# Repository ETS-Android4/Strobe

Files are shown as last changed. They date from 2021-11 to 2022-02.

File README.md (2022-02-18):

# Strobe
Repository contains Arduino program and Android application used for one of my physics projects in high school. The project was a device to show stroboscopic effect on a stream of water.
Embedded (Arduino) program controls the operation of the device like colors of RGB LEDs, electromagnet, water pump. Android app provides easy to use interface to remote change parameters (frequency, colors etc.) in realtime by bluetooth.

## Android app
| Home | Palette |
| - | - |
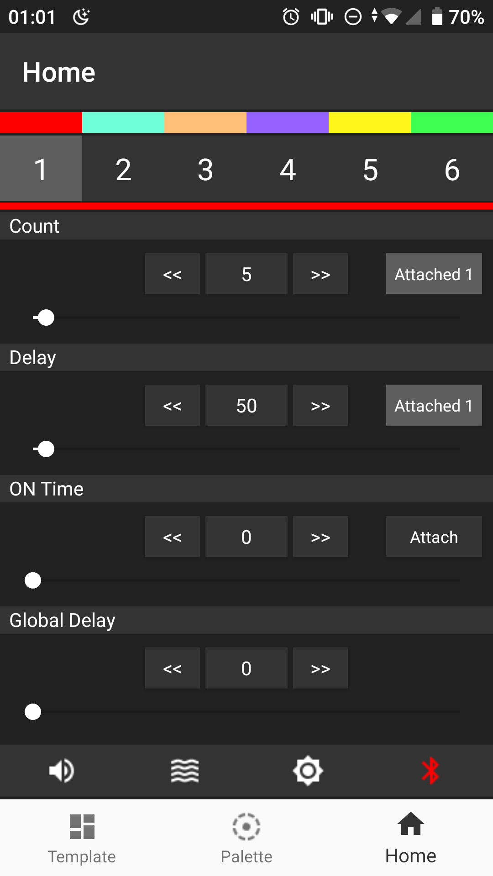
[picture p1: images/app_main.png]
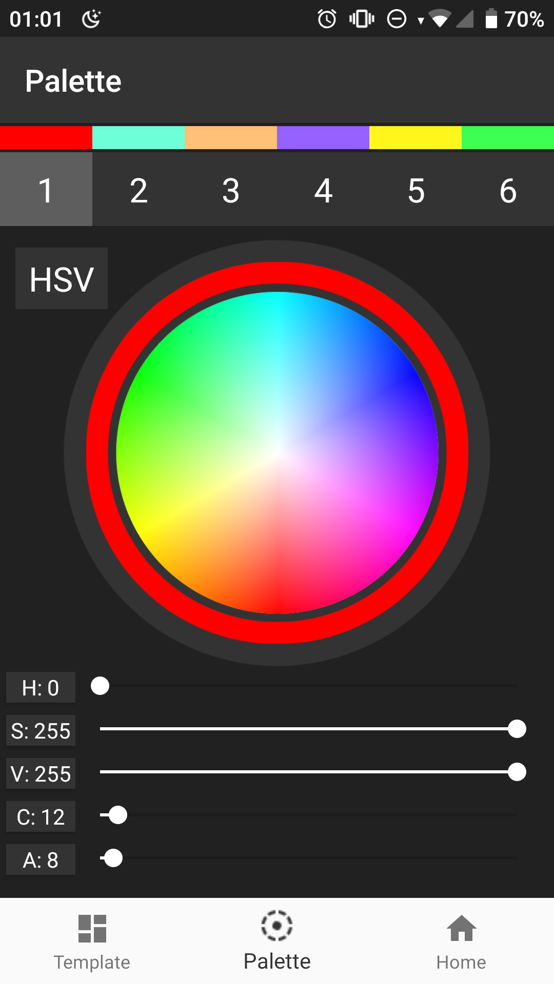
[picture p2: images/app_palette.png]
|  |  |

##### Android app tested only on Xiaomi mi A1

## Example of effects
| | | | |
|-|-|-| - |
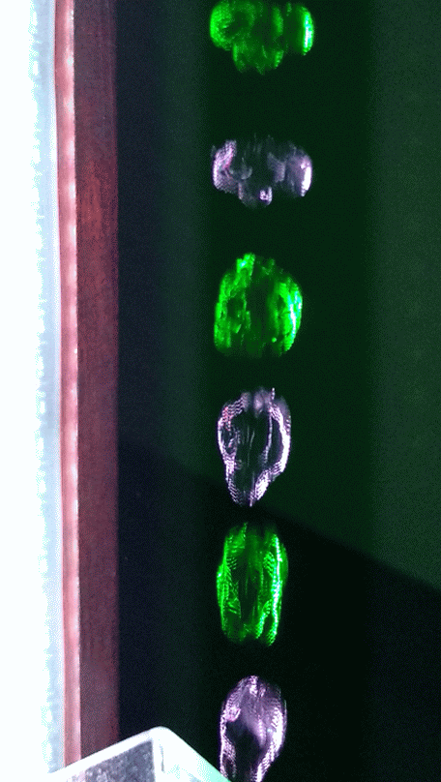
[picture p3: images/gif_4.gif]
| |  |  |  |

## Board

|||
|-|-|
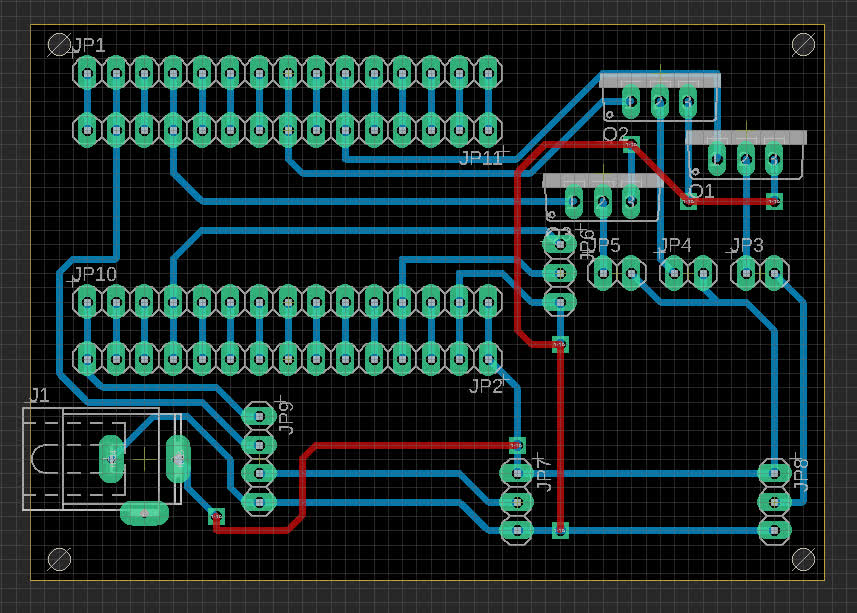
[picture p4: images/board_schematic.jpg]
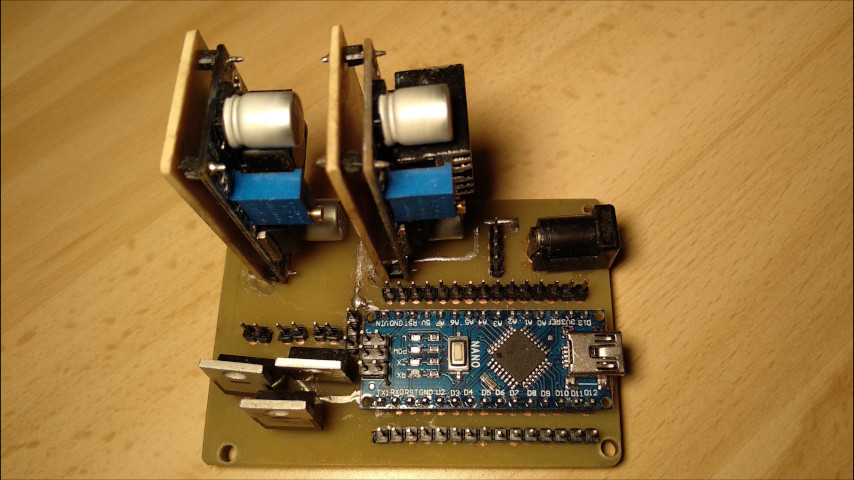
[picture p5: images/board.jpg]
|  | |

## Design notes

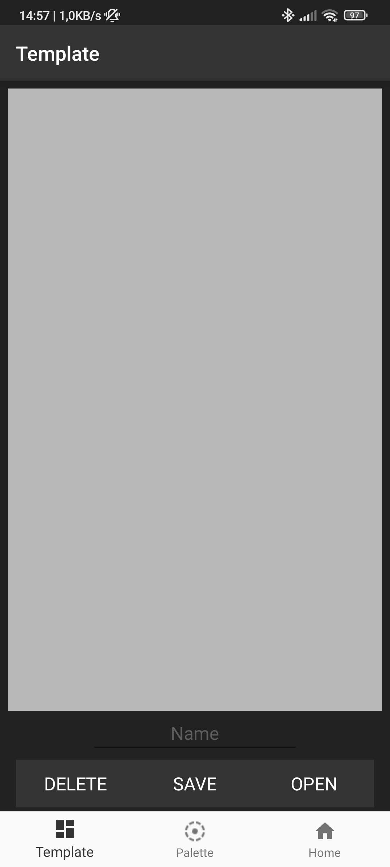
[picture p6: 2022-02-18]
images/app_template.jpg

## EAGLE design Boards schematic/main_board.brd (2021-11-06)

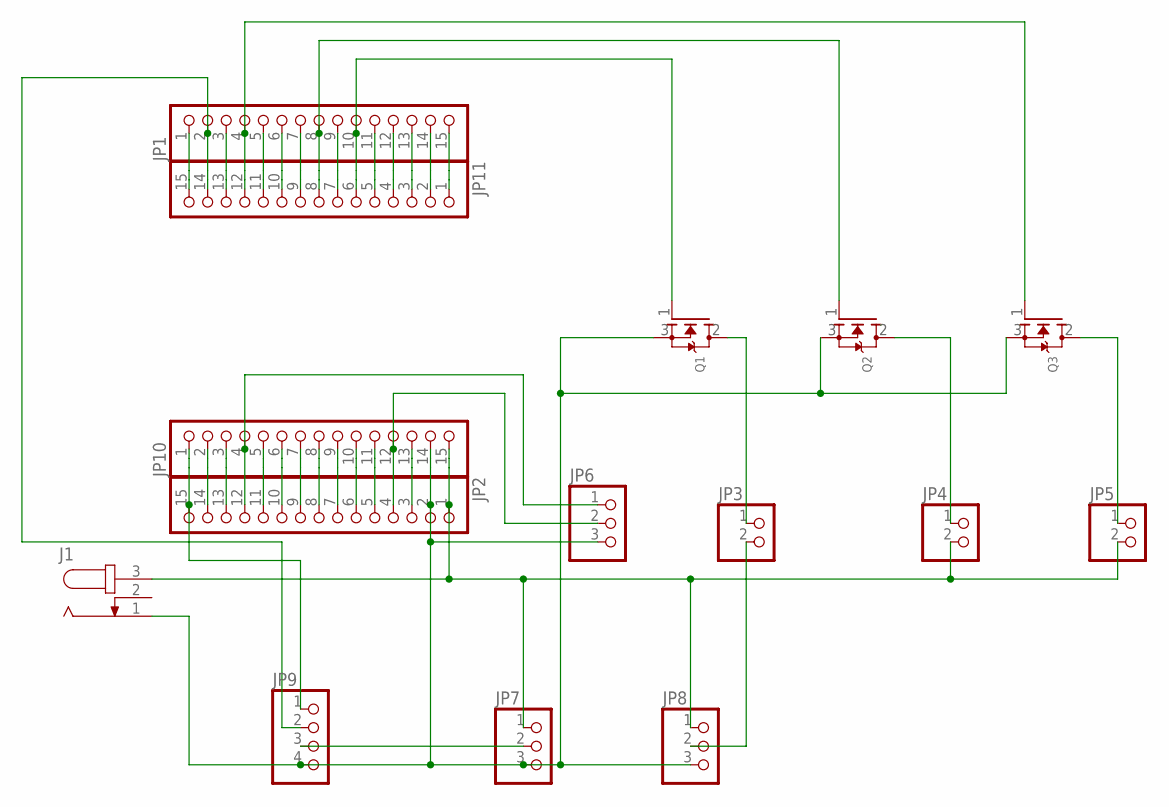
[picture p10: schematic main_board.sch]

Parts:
J1: JACK-PLUG1; SPC4078
JP1, JP2, JP10, JP11: PINHD-1X15; 1X15
JP3, JP4, JP5: PINHD-1X2; 1X02
JP6, JP7, JP8: PINHD-1X3; 1X03
JP9: PINHD-1X4; 1X04
Q1, Q2, Q3: MOSFET-NGDS_TO220V; TO220V

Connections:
unnamed: JP2.15, JP9.1, JP10.1
unnamed: JP2.14, JP10.2
unnamed: JP2.13, JP10.3
unnamed: JP2.12, JP6.1, JP10.4
unnamed: JP2.11, JP10.5
unnamed: JP2.10, JP10.6
unnamed: JP2.9, JP10.7
unnamed: JP2.8, JP10.8
unnamed: JP2.7, JP10.9
unnamed: JP2.6, JP10.10
unnamed: JP2.5, JP10.11
unnamed: JP2.4, JP6.2, JP10.12
unnamed: JP2.3, JP10.13
unnamed: J1.1, JP2.2, JP6.3, JP7.3, JP8.3, JP9.4, JP10.14, Q1.3 (S), Q2.3 (S), Q3.3 (S)
unnamed: J1.3, JP2.1, JP4.2, JP5.2, JP7.1, JP8.1, JP10.15
unnamed: JP1.15, JP11.1
unnamed: JP1.14, JP11.2
unnamed: JP1.13, JP11.3
unnamed: JP1.12, JP11.4
unnamed: JP1.11, JP11.5
unnamed: JP1.10, JP11.6, Q1.1 (G)
unnamed: JP1.9, JP11.7
unnamed: JP1.8, JP11.8, Q2.1 (G)
unnamed: JP1.7, JP11.9
unnamed: JP1.6, JP11.10
unnamed: JP1.5, JP11.11
unnamed: JP1.4, JP11.12, Q3.1 (G)
unnamed: JP1.3, JP11.13
unnamed: JP1.2, JP9.2, JP11.14
unnamed: JP1.1, JP11.15
unnamed: JP3.1, Q1.2 (D)
unnamed: JP4.1, Q2.2 (D)
unnamed: JP5.1, Q3.2 (D)
unnamed: JP3.2, JP8.2
unnamed: JP7.2, JP9.3

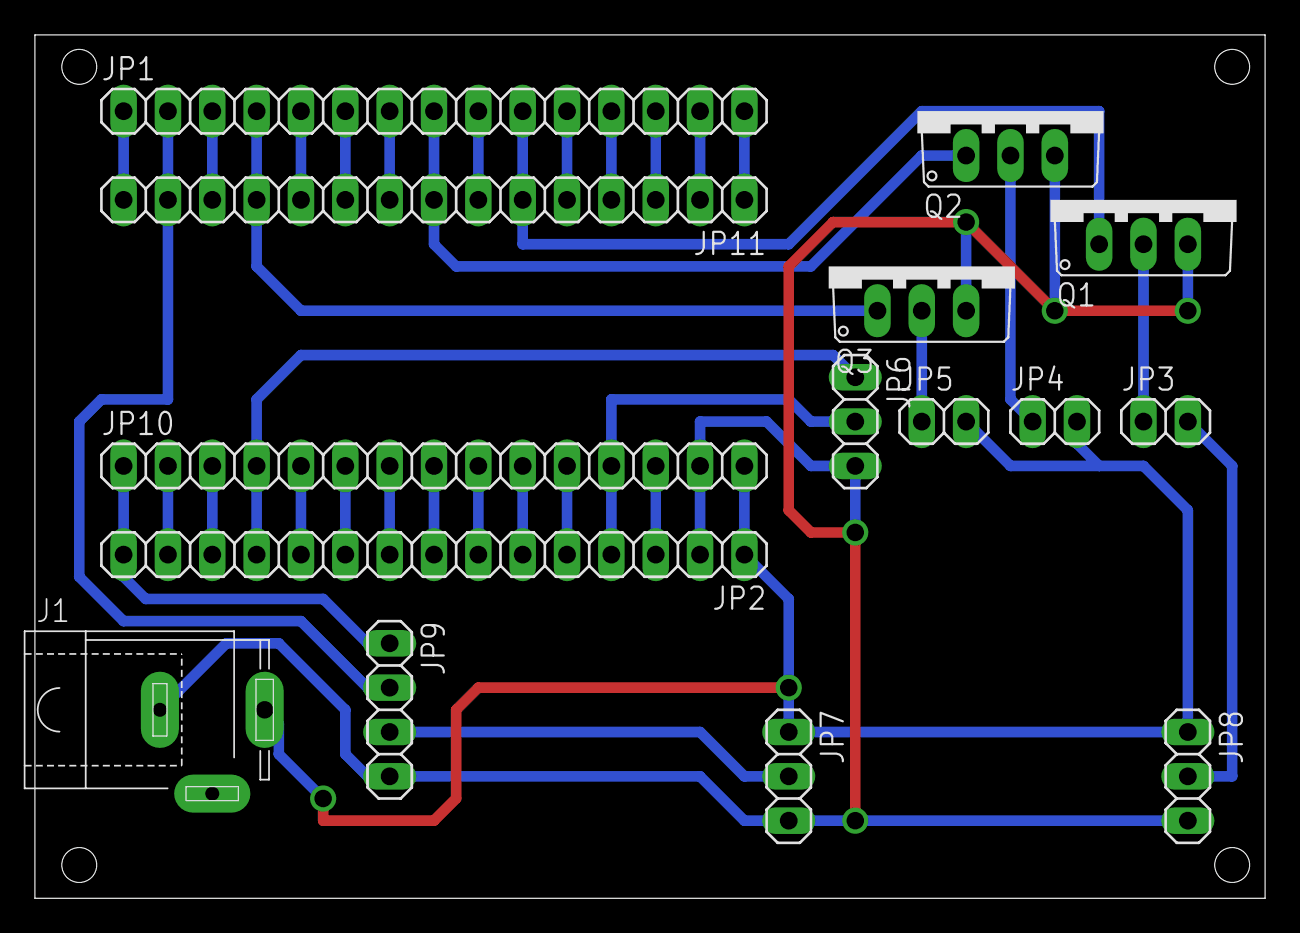
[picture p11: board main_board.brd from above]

Board: 2 copper layers, 70.5 x 49.5 mm, 15 parts (0 on the bottom side), 35 nets.

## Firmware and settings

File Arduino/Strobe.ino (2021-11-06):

#include <TimerOne.h>
#include <FastLED.h>

#define NP 64

#define Magnet 5
#define Pump 3

#define LED_max 20001

String string;
String sign;
char command, mark;
unsigned int l;
bool sync;

unsigned char colors[6][3], add_hsv[6]={0}, count_hsv[6]={1}, count[6]={2}, selected = 0, pumpValue, attachValue[8], c[6]={0}, add_color=0, mag=64;
unsigned short latency[6]={100}, onTime[6]={0}, global={1};
bool chosen[6], attachBool[8]= {false};
unsigned int pumpCount, ledCount=0, pot, x=1000;

int off, on;

CRGB leds[NP];
unsigned char startIndex = 0;
unsigned char brightness = 192;
bool LED = true;
bool model = true;
bool magnet = true;
bool pump = true;
bool Sync = false;

unsigned char magValue = 48;

void setup()
{
  chosen[0] = true;
  count[0]=2;
  latency[0]=1600;
  colors[0][0]=0;
  colors[0][1]=0;
  colors[0][2]=255;
 
  delay(1000);
  pinMode(Magnet, OUTPUT);
  pinMode(Pump, OUTPUT);
  
  FastLED.addLeds<APA102, 11, 13, BGR, DATA_RATE_MHZ(12)>(leds, NP);
  FastLED.setBrightness(192);
  
  Serial.begin(9600);
  Serial.setTimeout(200);

  Timer1.initialize(500);
  Timer1.attachInterrupt(pump_thread);
  
  delay(1000);  
}

void pump_thread(void){
  if(pump){
   if(pumpValue){
      if(pumpCount==pumpValue){
       digitalWrite(Pump, HIGH);}
     if(pumpCount>=40){
       digitalWrite(Pump, LOW);
       pumpCount=0;}
       pumpCount++;
    }
    else
      digitalWrite(Pump, HIGH);
  }
  else
    digitalWrite(Pump, LOW);
}

//Bluetooth
void Bluetooth(){
  if (Serial.available() > 0){
      string = "";
      l=0;
      mark = "";}
  while(Serial.available() > 0){
    command = ((byte)Serial.read());
    if(command == 'x')
      break;
    else{
      string += command;}
    delay(1);
  }
  Read();
  /*if(string!=""){
    Serial.print("String: "); Serial.println(string[string.length()-1]);
    Serial.print("Number: "); Serial.println(string.toInt());
  }*/
}

void Read(){
  mark = string[string.length()-1];
  l = string.toInt();
  switch(mark){
    case 'Q': switch(l){
      case 0: LED = true; break;
      case 1: LED = false; break;
      case 2: magnet = true; break;
      case 3: magnet = false; break;
      case 4: pump = true; break;
      case 5: pump = false; break;
      case 6: Sync = true; break;
      case 7: Sync = false; break;
    }
    //menu
    case 'b': brightness = l; FastLED.setBrightness(l); break;
    case 'p': pumpValue=l; break;
    case 'm': magValue=l; break;

    case 'P': x = l; break;
    //Palette
    case 'R': colors[selected][0] = l; break;
    case 'G': colors[selected][1] = l; break;
    case 'B': colors[selected][2] = l; break;
    case 'h': count_hsv[selected] = l; break;
    case 'v': add_hsv[selected] = l; c[selected]=0; break;
    //Home
    case 'S': selected = l; break;
    case 'A': for(int i=1; i<7;i++) {sign = string[i]; chosen[i-1]=sign.toInt();} break;
    case 'c': count[selected] = l; break;
    case 'd': latency[selected] = l; break;
    case 'o': onTime[selected] = l; break;
    case 'g': global = l; break;
    //Home attach
    case 'C': for(int i=1; i<9; i++){
      if(string[i]!='9'){
        attachBool[i-1]=true; sign = string[i]; attachValue[i-1]=sign.toInt();
      }else{attachBool[i-1]=false;}
      }break;
    case 'O': add_color = l; break;
  }
  l=0;
  mark = "";
  string = "";
}

void ledFunction(){
  char i=0, colorBuffer[3]={0}, countBuffer=0, latencyBuffer=0, onBuffer=0, hBuffer=0, aBuffer=0;
  
      if(attachBool[0]){
        countBuffer = attachValue[0];}
      if(attachBool[1]){
        latencyBuffer = attachValue[1];}
      if(attachBool[2]){
        onBuffer = attachValue[2];}
      if(attachBool[3]){
        colorBuffer[0] = 0;}
      if(attachBool[4]){
        colorBuffer[1] = 0;}
      if(attachBool[5]){
        colorBuffer[2] = 0;}
      if(attachBool[6]){
        hBuffer = 0;}
      if(attachBool[7]){
        aBuffer = 0;}
        
  if(LED){
    while(i<6){
      if(ledCount%count[countBuffer]==1){
        if(chosen[i]){
          fill_solid(leds, NP, CHSV(colors[colorBuffer[0]][0]+c[i]+add_color*(i), colors[colorBuffer[1]][1], colors[colorBuffer[2]][2]));
          FastLED.show();
          delayMicroseconds(onTime[onBuffer]*10);
        }else{
          //delayMicroseconds(824);
        }
        FastLED.clear();
        FastLED.show();
        delayMicroseconds(latency[latencyBuffer]*10);
      }
      if(count_hsv[hBuffer]==1||add_hsv[aBuffer]==0){
         c[i]=0;}
      if(ledCount%count_hsv[hBuffer]==1){
        c[i]+=add_hsv[aBuffer];}
      i++;
      
      if(!attachBool[0]){
        countBuffer++;}
      if(!attachBool[1]){
        latencyBuffer++;}
      if(!attachBool[2]){
        onBuffer++;}
      if(!attachBool[3]){
        colorBuffer[0]++;}
      if(!attachBool[4]){
        colorBuffer[1]++;}
      if(!attachBool[5]){
        colorBuffer[2]++;}
      if(!attachBool[6]){
        hBuffer++;}
      if(!attachBool[7]){
        aBuffer++;}
      
      }
  }
  delayMicroseconds(global*10);
  FastLED.clear();
  FastLED.show();
}

void pokaz(){
  switch(x){
    case 0:
      if(brightness<192){
        if(ledCount%10==1){
          brightness+=3;
          FastLED.setBrightness(brightness);} 
      }
      break;
    case 1:
      FastLED.setBrightness(192);
      if(onTime[0]<1300){
        if(ledCount%3==1){
          onTime[0]+=10;
          latency[0]-=10;} 
      }
      break;
    case 2:
      onTime[0] = 0;
      count[0] = 5;
      latency[0]=49;
      add_color=43;
      string = "100000000C";
      Read();
      string = "1111111A";
      Read();
      x=100;
      break;
    case 3:
      if(colors[0][1]<255){
        if(ledCount%4==1){
          colors[0][1]+=1;} 
      }
      break;
    case 4:
      count_hsv[0] = 12;
      add_hsv[0]=8;
      x=100;
      break;
    case 5:
      count[0]=2;
      latency[0]=0;
      if(ledCount%8==1){
        if(onTime[0]<100)
          onTime[0]+=5;
        else{
          if(add_hsv[0]>10)
            add_hsv[0]--;
          if(count_hsv[0]<24)
            count_hsv[0]++;
          if(add_color>15)
            add_color-=1;
        }
      }
      break;
    case 6:
      if(ledCount%4==1){
        if(colors[0][2]>0)
          colors[0][2]-=5;
      }
      break;
    case 7:
      add_hsv[0] = 8;
      onTime[0]=0;
      count[0]=4;
      count_hsv[0] = 20;
      latency[1]=0; latency[0]=774;
      count[1]=4; c[0]=0; c[1]=0;
      add_color = 128;
      string = "109900009C";
      Read();
      string = "1110000A";
      Read();
      x = 8;
      break;
    case 8:
      if(ledCount%4==1){
        if(colors[0][2]<255)
          colors[0][2]+=5;
      }
      break;
  }
}

void wait(){
  startIndex++;
  char colorIndex = startIndex;
  for( int i = 0; i < NP/2; i++) {
        leds[i] = ColorFromPalette(RainbowColors_p, colorIndex, 80, LINEARBLEND);
        leds[NP-i] = ColorFromPalette(RainbowColors_p, colorIndex, 80, LINEARBLEND);
    colorIndex += 3;
    }
  FastLED.show();
  delayMicroseconds(125);
  FastLED.clear();
  FastLED.show();
  delayMicroseconds(3950);
}

void templates(){
  switch(pot/100){
      case 0:
      case 1:
      case 2:
        if(!Sync){
          ledFunction();
        }
        else{
          wait();
        }
        break; 
      case 3:
        FastLED.setBrightness(192);
        fill_solid(leds, NP, CHSV(0, 0, 255));
        FastLED.show();
        FastLED.clear();
        FastLED.show();
        delayMicroseconds(16363);
        delayMicroseconds(2390);
        break;
      case 4:
        for(int i =0; i<11; i++){
          fill_solid(leds, NP, CHSV(0, 0, 255/i));
          FastLED.show();
          FastLED.clear();
          FastLED.show();
        }
        break;
      case 5:
        break;
      case 6:
        wait();
        break;
      case 7:
        off=420; on=1600;
        fill_solid(leds, NP, CRGB(255, 0, 0));
        FastLED.show();
        delayMicroseconds(on);
        FastLED.clear();
        FastLED.show();
        fill_solid(leds, NP, CRGB(255, 55, 0));
        FastLED.show();
        delayMicroseconds(on);
        FastLED.clear();
        FastLED.show();
        fill_solid(leds, NP, CRGB(255, 203, 0));
        FastLED.show();
        delayMicroseconds(on);
        FastLED.clear();
        FastLED.show();
        fill_solid(leds, NP, CRGB(0, 255, 0));
        FastLED.show();
        delayMicroseconds(on);
        FastLED.clear();
        FastLED.show();
        fill_solid(leds, NP, CRGB(0, 0, 255));
        FastLED.show();
        delayMicroseconds(on);
        FastLED.clear();
        FastLED.show();
        fill_solid(leds, NP, CRGB(123, 0, 255));
        FastLED.show();
        delayMicroseconds(on);
        FastLED.clear();
        FastLED.show();
        delayMicroseconds(off);
        break;
      case 8:
        FastLED.setBrightness(192);
        fill_solid(leds, NP, CHSV(0, 0, 255));
        FastLED.show();
        FastLED.clear();
        FastLED.show();
        delayMicroseconds(16363);
        delayMicroseconds(2390);
        break;  
    }
}

void loop(){
  Bluetooth();
  pokaz();
  /*if(pump){
      digitalWrite(Pump, HIGH);}
    else{
      digitalWrite(Pump, LOW);
  }*/
  if(pot!=analogRead(A0)){
    pot = analogRead(A0);
  }
  bool flag;
  if(pot>900){
    FastLED.setBrightness(15);
    fill_gradient_RGB(leds, 32, CRGB(48,48,48), 63, CRGB(170,255,0));
    fill_gradient_RGB(leds, 0, CRGB(170,255,0), 31, CRGB(48,48,48));
    FastLED.show();
    noTone(Magnet);
    mag=64;
  }
  else{
    if(!magnet){
      noTone(Magnet);
      mag=64;
    } else {
      if(mag>48){
        if(ledCount%20==1){
          tone(Magnet, mag);
          mag-=1;} 
      }else
        tone(Magnet, magValue);
    }
    templates();   
  }
  ledCount++;
  if(ledCount>LED_max){
    ledCount=0;}
}

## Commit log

2021-11-06 Upload boards schematics and arduino ino
    [converter.brd, converter.sch, main_board.brd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]
2022-05-29 Push SonarCloud config file.
